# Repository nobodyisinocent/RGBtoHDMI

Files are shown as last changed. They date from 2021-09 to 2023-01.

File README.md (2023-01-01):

# Table of contents
1. [What is the RGBtoHDMI board](#1)
2. [Tiny RGB2HDMI CPLD design](#2)
3. [Low profile board based on design from c0pperdragon](#3)
    1. [CTDV board !](#3.1)
    2. [AMIGA 500 boards](#3.2)

# What is the RGBtoHDMI board 
The RGBtoHDMI device adds an HDMI output to your AMIGA only in OCS display mode thanks to the use of a Raspberry Pi0.
The very first RGB2HDMI design has been made by c0pperdragon. It can be found here:

https://github.com/c0pperdragon/Amiga-Digital-Video/

Originally, I made my own version since I wanted the smallest possible pcb for my personnal use, and also for the use of my friend Lolof.
The aim of these designs is to allow the combined use of the RGB2HDMI and others expansions as accelerator boards for example like the big board of the Mega Midget Racer.

Here, you'll find the three lowprofile following versions of the RGBtoHDMI I designed with Kicad and FreeRooting under Linux.

# Tiny RGB2HDMI CPLD design 
Always with the same goal, as small as possible, this board uses the CPLD Rev1.1 design from solarmon. But, since the configuration menu is accessible with one button, the 3 buttons and the OSD connector (no interest for my use) have been removed.

The firmware can be downloaded onto the official Github of the original CPLD version from hoglet67 here:

https://github.com/hoglet67/RGBtoHDMI/releases

To install the firmware, as for the first version of the RGBtoHDMI, simply extract the files to the µ-SD card's root and follow the instruction from Amiga_Readme.txt inside the Amiga_CPLD_Setup directory.

Here some pictures from Lolof of the Tiny CPLD RGBtoHDMI installed onto an A500 with the excellent TK030 from Matze !

1633015126219_resultat

1633015126210_resultat

1633026660919_resultat

1633026660925_resultat

# Low profile board based on design from c0pperdragon 

## CDTV board 

Here is the version specially designed for the CDTV.
The goal is always the same,having a nice and small board. :-)





IMG_20210501_222826_resultat

IMG_20210501_224244_resultat

IMG_20210501_225041_resultat

IMG_20210501_225333_resultat

IMG_20210501_225625_resultat

1615405848653_resultat

1615405848665_resultat

## AMIGA 500 boards 

Two designs versions have been done. Here they are:

First design with Pi0 located between CIA and PAULA:
V4

Second version, the smallest design version with the Pi0 installed just onto CIA with HDMI output on the back of the AMIGA.
It was special request of my friend Lolof, and perhaps the best one of the two A500 design:


And some pictures from Lolof of this second version rgb2hdmi in action onto his A500 !













And the first version onto my A500+ Red edition used with the Vampire V2+!

IMG_20210501_200834_resultat

IMG_20210501_200843_resultat

I hope you'll enjoy these versions of this great device !

-Tuxbar81

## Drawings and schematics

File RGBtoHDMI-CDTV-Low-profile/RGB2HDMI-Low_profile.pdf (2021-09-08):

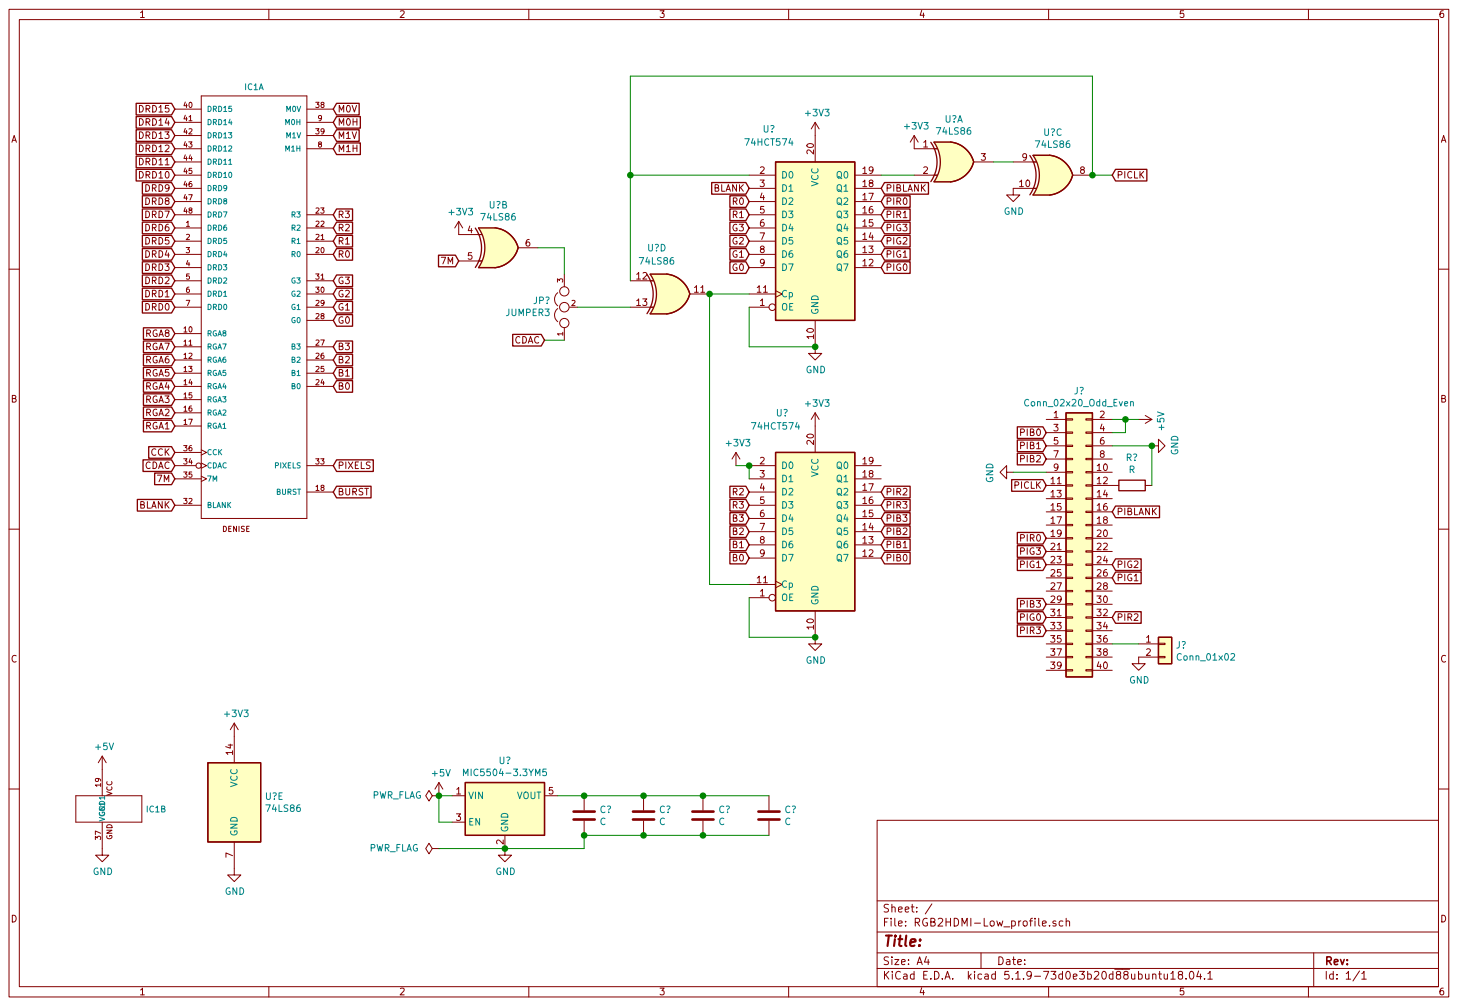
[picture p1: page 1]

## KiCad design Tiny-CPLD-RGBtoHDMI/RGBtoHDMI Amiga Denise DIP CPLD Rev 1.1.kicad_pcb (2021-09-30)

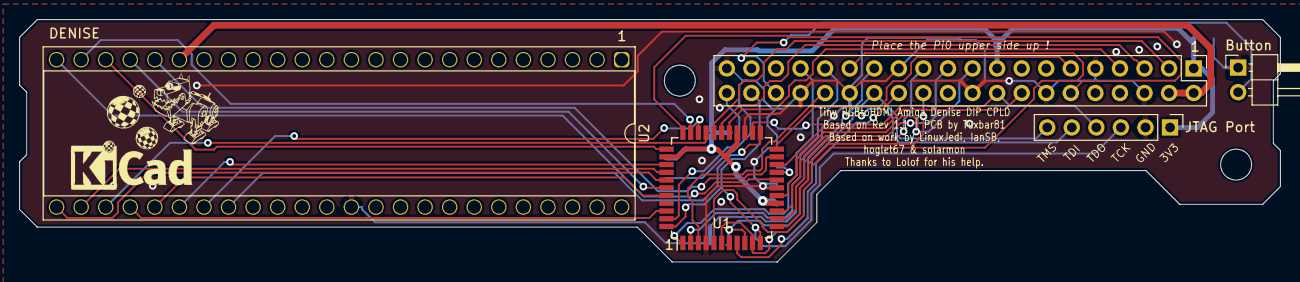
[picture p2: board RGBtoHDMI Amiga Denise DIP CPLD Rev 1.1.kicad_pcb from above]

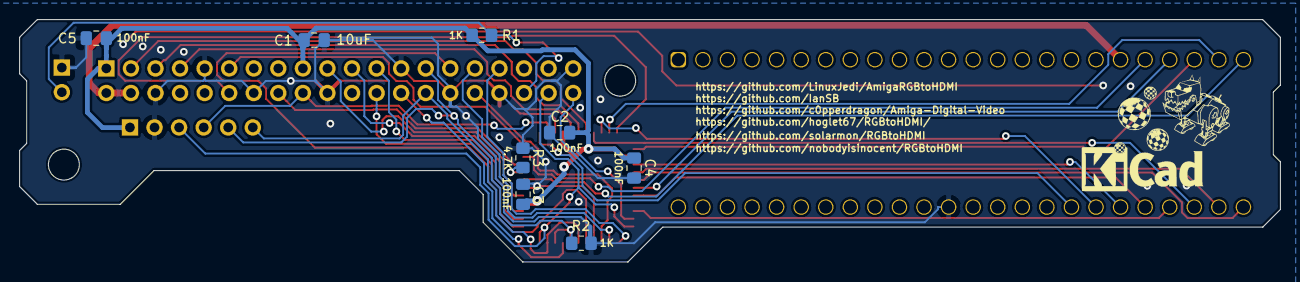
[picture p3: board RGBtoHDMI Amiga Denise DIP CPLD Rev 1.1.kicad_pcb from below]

Board: 2 copper layers, 130.3 x 25.1 mm, 13 parts (8 on the bottom side), 38 nets.

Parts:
Button: Jumper_2_Open; PinHeader_1x02_P2.54mm_Horizontal
C1: 10uF; C_0805_2012Metric_Pad1.18x1.45mm_HandSolder
C2, C3, C4, C5: 100nF; C_0805_2012Metric_Pad1.18x1.45mm_HandSolder
J1: Raspberry_Pi_2_3; PinSocket_2x20_P2.54mm_Vertical
JTAG Port: Pin_Header_Straight_1x06_Pitch2.54mm
R1, R2: 1K; R_0805_2012Metric_Pad1.20x1.40mm_HandSolder
R3: 4.7K; R_0805_2012Metric_Pad1.20x1.40mm_HandSolder
U1: XC9572VQ44 or XC9572XL-10VQG44C; TQFP-44_10x10mm_P0.8mm
U2: DENISE; DIP-48_W15.24mm_Socket

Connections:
+3V3: C1.1, C2.1, C3.1, C4.1, C5.1, J1.1, J1.17, JTAG Port.1, R1.1, U1.15, U1.26, U1.35
+5V: J1.2, J1.4, U2.19
/B0: U1.18, U2.24
/B1: U1.38, U2.25
/B2: U1.37, U2.26
/B3: U1.30, U2.27
/CLKEN: J1.28, JTAG Port.6, U1.6, U1.10
/CSYNC: U1.23, U2.32
/DETECT: R3.1, U1.19
/G0: U1.42, U2.28
/G1: U1.40, U2.29
/G2: U1.36, U2.30
/G3: U1.31, U2.31
/GPIO0: J1.27, JTAG Port.5, R2.1, U1.7, U1.9
/GPIO2: J1.3, U1.29
/GPIO3: J1.5, U1.28
/GPIO4: J1.7, U1.27
/GPIO5: J1.29, U1.5
/GPIO6: J1.31, U1.2
/GPIO7: J1.26, U1.8
/GPIO8: J1.24, U1.12
/GPIO9: J1.21, U1.14
/GPIO10: J1.19, U1.16
/GPIO11: J1.23, U1.13
/GPIO12: J1.32, U1.3
/GPIO13: J1.33, U1.1
/GPIO16: Button.2, J1.36, R1.2
/GPIO17: J1.11, U1.22
/GPIO18: J1.12, U1.33
/GPIO20: J1.38, JTAG Port.3, U1.11, U1.44
/GPIO21: J1.40, U1.43
/GPIO23: J1.16, U1.20
/GPIO24: J1.18, JTAG Port.4, U1.24
/R0: U1.21, U2.20
/R1: U1.39, U2.21
/R2: U1.34, U2.22
/R3: U1.32, U2.23
GND: Button.1, C1.2, C2.2, C3.2, C4.2, C5.2, J1.6, J1.9, J1.14, J1.20, J1.25, J1.30, J1.34, J1.39, JTAG Port.2, R2.2, R3.2, U1.4, U1.17, U1.25, U2.37

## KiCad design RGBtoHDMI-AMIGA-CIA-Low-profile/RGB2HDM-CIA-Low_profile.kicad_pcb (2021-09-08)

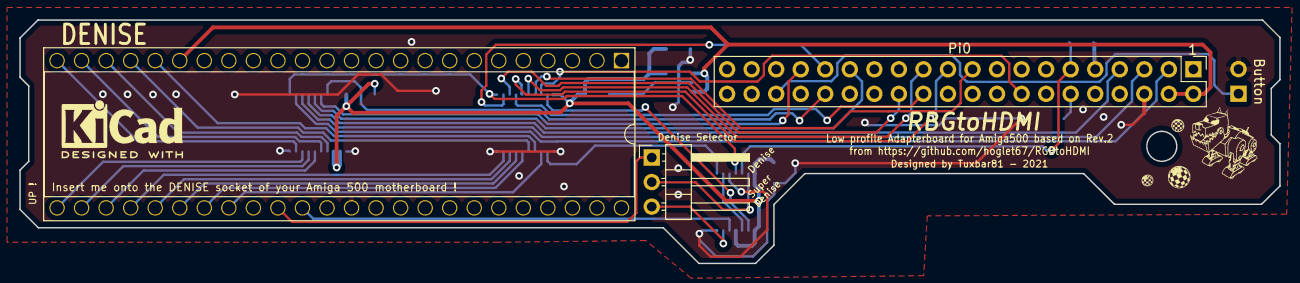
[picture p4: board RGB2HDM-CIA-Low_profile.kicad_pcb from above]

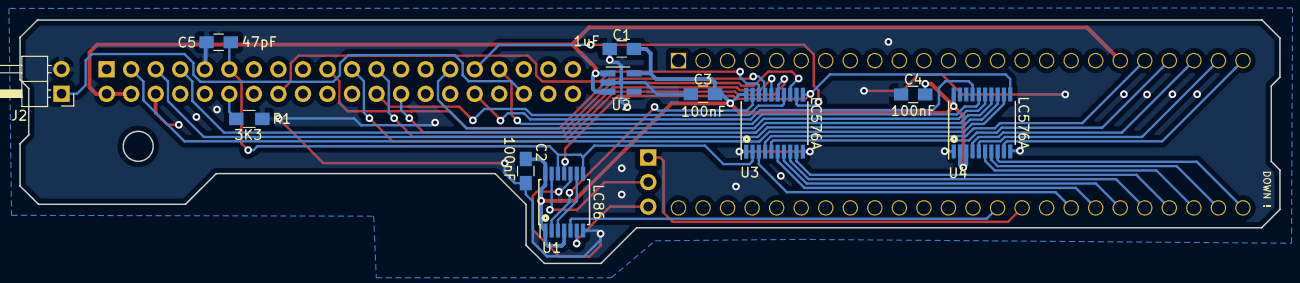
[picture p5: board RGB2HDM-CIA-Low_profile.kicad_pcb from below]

Board: 2 copper layers, 130.4 x 25.2 mm, 14 parts (11 on the bottom side), 39 nets.

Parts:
C1: 1uF; C_0805_HandSoldering
C2, C3, C4: 100nF; C_0805_HandSoldering
C5: 47pF; C_0805_HandSoldering
DENISE: DENISE_DIP-LABEL; DIP-48_W15.24mm_Socket
Denise Selector: JUMPER3; Pin_Header_Angled_1x03_Pitch2.54mm
J2: Conn_01x02; Pin_Header_Angled_1x02_Pitch2.54mm
Pi0: Conn_02x20_Odd_Even; Pin_Header_Straight_2x20_Pitch2.54mm
R1: 3K3; R_0805_HandSoldering
U1: LC86; TSSOP-14_4.4x5mm_Pitch0.65mm
U2: TLV70033_SOT23-5; SOT-23-5_HandSoldering
U3, U4: LC576A; TSSOP-20_4.4x6.5mm_Pitch0.65mm

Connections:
7M: DENISE.35, U1.5
+3V3: C1.1, C2.1, C3.1, C4.1, U1.1, U1.4, U1.14, U2.5, U3.20, U4.2, U4.3, U4.20
+5V: DENISE.19, Pi0.2, Pi0.4, U2.1, U2.3
B0: DENISE.24, U4.9
B1: DENISE.25, U4.8
B2: DENISE.26, U4.7
B3: DENISE.27, U4.6
BLANK: DENISE.32, U3.3
CDAC: DENISE.34, Denise Selector.1
G0: DENISE.28, U3.9
G1: DENISE.29, U3.8
G2: DENISE.30, U3.7
G3: DENISE.31, U3.6
GND: C1.2, C2.2, C3.2, C4.2, C5.2, DENISE.37, J2.2, Pi0.6, Pi0.9, R1.2, U1.7, U1.10, U2.2, U3.1, U3.10, U4.1, U4.10
unnamed: Pi0.12, R1.1
unnamed: J2.1, Pi0.36
unnamed: Denise Selector.2, U1.13
unnamed: Denise Selector.3, U1.6
unnamed: U1.2, U3.19
unnamed: U1.3, U1.9
unnamed: U1.11, U3.11, U4.11
PIB0: Pi0.3, U4.12
PIB1: Pi0.5, U4.13
PIB2: Pi0.7, U4.14
PIB3: Pi0.29, U4.15
PIBLANK: Pi0.16, U3.18
PICLK: C5.1, Pi0.11, U1.8, U1.12, U3.2
PIG0: Pi0.31, U3.12
PIG1: Pi0.26, U3.13
PIG2: Pi0.24, U3.14
PIG3: Pi0.21, U3.15
PIR0: Pi0.19, U3.17
PIR1: Pi0.23, U3.16
PIR2: Pi0.32, U4.17
PIR3: Pi0.33, U4.16
R0: DENISE.20, U3.4
R1: DENISE.21, U3.5
R2: DENISE.22, U4.4
R3: DENISE.23, U4.5

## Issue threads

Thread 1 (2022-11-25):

FR looking for a older design

jmp49152, 2022-11-25:
Bonjour,
Sorry to raise this as a issue but README/profile has no contact email etc.
I'm interested in a older project you did to replicate the megachip adapter for the Amiga 2000 vendu on Amibay, I understand you may no longer be producing these but would you consider uploading this adapter project to github also?
A+
jmp49152

jmp49152, 2022-11-25:
I found Andrew Hutchings repo with a device with the above functionality, so I'll close this and not bother you.
Merci ;)

Closed 2022-11-25.
